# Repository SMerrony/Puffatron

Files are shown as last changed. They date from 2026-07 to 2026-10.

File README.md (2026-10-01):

# The Puffatron
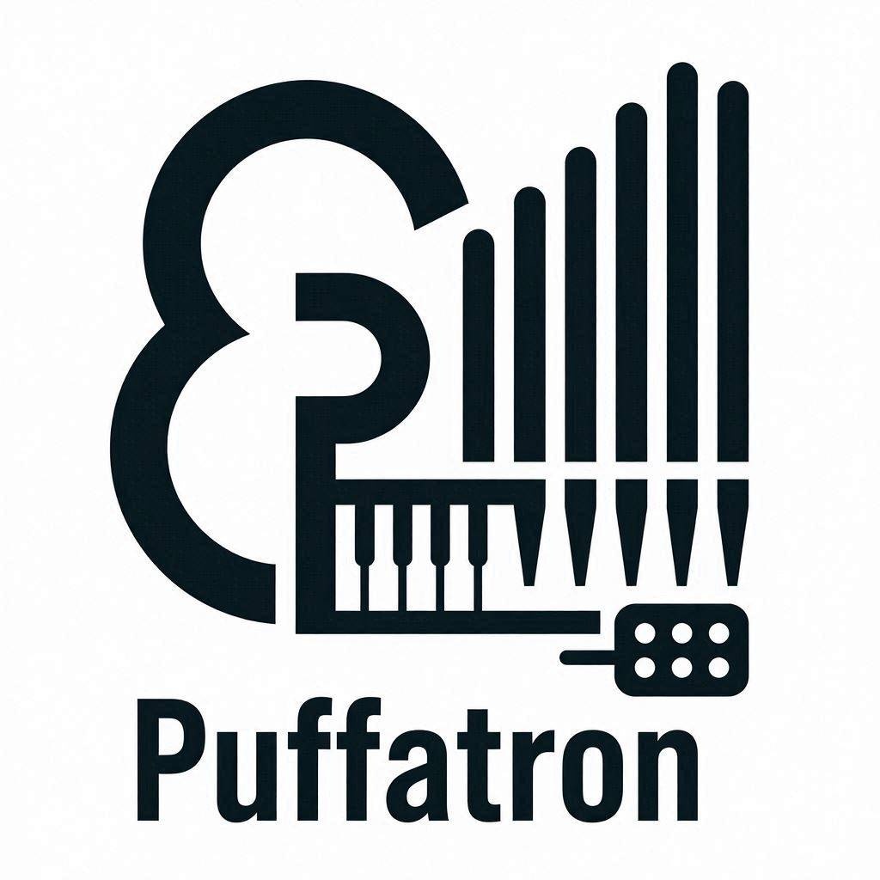
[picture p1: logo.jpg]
Puffatron Logo


The Puffatron is a mostly 3D printed USB MIDI-controlled pipe organ rank.

It can be used as a standalone USB-MIDI player, connected to MIDI keyboards to create a hybrid electronic/physical pipe organ, or added to an existing instrument as an extension.

## Features
* Easy to configure
* Active pipe display - a bit like a VU meter
* Relatively low-cost
* All the 3D printed parts are printable on a reasonably common domestic 3D printer eg. an Ender-3 KE
* All the off-the-shelf parts are easily obtainable
* Use either off-the-shelf breadboards, or a custom PCB

## Configuration
The configuration is stored in the `settings.toml` file.  All of the following settings are required...

* __MIDI_CHANNEL__ - which MIDI channel should this Puffatron play
* __LOWEST_NOTE__ - MIDI note number of lowest note playable on this Puffatron
* __HIGHEST_NOTE__ - MIDI note number of highest note playable on this Puffatron
* __DEBUG__ - set to `false` for production, `true` for development - controls debug messages, slows responsiveness of Puffatron

## Off-the-shelf Parts
* 12V or 5V mini-solenoids (one per pipe)
* WaveShare RP2040-Zero (or close equivalent)
* Adafruit PCA9685 16-channel PWM driver module (one for each 16 pipes)
* ULN2803A Darlington array (two for each 16 pipes)
* SSD1306 OLED display
* Blower...
* PSU...
* Breadboards

## 3D Printed Parts
* Windchest
* Blower box
* Pipe feet (whistles)
* Tuning slides (or corks?)
  
## Miscellaneous Parts
* Neoprene sheet
* Medium-sized metal-cored paperclips (one per pipe)
* Hook-up wire for breadboard and solenoids

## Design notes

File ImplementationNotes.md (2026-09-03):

# Puffatron

## Concept
A rank of 3D printed organ pipes, on a 3D printed wind-chest controlled via standard USB MIDI.
With 16 available MIDI channels, we could theoretically have 16 ranks/Puffatrons!

The goal is that all the 3D printed parts should be printable on a reasonably common domestic 3D printer eg. an Ender-3 KE.

## Microcontroller
The inexpensive WaveShare RP2020-PiZero has been chosen for the project.  Many similar "pico zero" type controllers should work equally well.

To handle the desired 49 - 56 notes per rank, best to use 3 expanders and some built-in GPIOs.

The 3D-printed windchest seems to max out at 33 pipes (on a 210x210mm print bed).  Maybe we could add a smaller extension to provide the full 49 - 56 pipes, i.e. an extra 16 - 23 pipes.

## Software/Firmware
As the required functionality is quite simple I have chosen to use CircuitPython which provides all the libraries needed (eg. USB MIDI, PCA9685).

## Configuration
See the README.md
  
## Wiring Conventions
By establishing the following conventions we eliminate the need for complex configuration files...

### Pipe Wiring (solenoids)
* It is assumed that all notes between HIGHEST_NOTE and LOWEST_NOTE exist.
* The LOWEST_NOTE should play via the first GPIO pin on the microcontroller.
* The next 7 notes then play sequentially on GPIO1 - GPIO7.
* If there are more than 8 notes playable, the 9th plays via the first GPIO pin of the first I2C expander.
* If there are more than 24 notes playable, the 25th plays via the first GPIO pin of the second I2C expander.
* If there are more than 40 notes playable, the 41st plays via the first GPIO pin of the third I2C expander.

### I2C Wiring
We use two I2C channels, one for the PCA9685 expanders, and one for the SSD1306 OLED display.
* The expanders connect to GPIO 28 and 29
* The display connects to GPIO 26 and 27

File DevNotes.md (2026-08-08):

# Puffatron

## Concept
A rank of 3D printed organ pipes, on a 3D printed wind-chest controlled via standard USB MIDI.
With 16 available MIDI channels, we could theoretically have 16 ranks/Puffatrons!

The goal is that all the 3D printed parts should be printable on a reasonably common domestic 3D printer eg. an Ender-3 KE.

## Microcontroller
The inexpensive WaveShare RP2020-PiZero has been chosen for the project.  Many similar "pico zero" type controllers should work equally well.

Each RP2040-Zero could potentially handle...

* 20 GPIOs using the pins only - not the pads*
* 48 GPIOs using 3 x MCP23017 16-way I2C GPIO expanders
* 66 GPIOs using 3 expanders and 18 pins
* 146 GPIOs using 8 expanders and 18 pins
* (290 GPIOs using 16 expanders (2 I2C channels) and 16 pins!)

\* But not on a standard breadboard - you can only use the 'side' pins, not the bottom ones.  The same applies to all the figures - subtract 5 local GPIOs from each count if using an off-the-shelf breadboard rather than the PCB

To handle the desired 49 - 56 notes per rank, best to use 3 expanders and some built-in GPIOs.

The 3D-printed windchest seems to max out at 33 pipes (on a 210x210mm print bed).  Maybe we could add a smaller extension to provide the full 49 - 56 pipes, i.e. an extra 16 - 23 pipes.

## Software/Firmware
As the required functionality is quite simple I have chosen to use CircuitPython which provides all the libraries needed (eg. USB MIDI, MCP23017).

## Configuration
See the README.md
  
## Wiring Conventions
By establishing the following conventions we eliminate the need for complex configuration files...

### Pipe Wiring (solenoids)
* It is assumed that all notes between HIGHEST_NOTE and LOWEST_NOTE exist.
* The LOWEST_NOTE should play via the first GPIO (GPA0) pin on the first I2C expander.
* The notes then play sequentially on that expander.
* If there are more than 16 notes playable, the 17th plays via the first GPIO pin of the second I2C expander.
* If there are more than 32 notes playable, the 33rd plays via the first GPIO pin of the third I2C expander.
* If there are more than 48 notes playable, the 47th plays via GPIO 0 on the microcontroller

### I2C Wiring
We use two I2C channels, one for the MCP23017 expanders, and one for the SSD1306 OLED display.
* The expanders connect to GPIO 28 and 29
* The display connect to GPIO 26 and 27

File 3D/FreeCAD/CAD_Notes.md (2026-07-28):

# Puffatron

## FreeCAD
Currently using FreeCAD v1.1.0

## Changes

### Action Prototype 3 2026-07-22
* Remove lever pad lip
* Chamfer wind tube

### Action Prototype 2 2026-07-22
* Add spring holes to lever and chest
* Add spring guide guide to lever
* Slightly increase hole size for solenoid
* Reduce lever length by 3mm
* Reduce some walls to 1.6mm (from 2mm)
* Increase axle holes to 2mm (from 1.8mm)

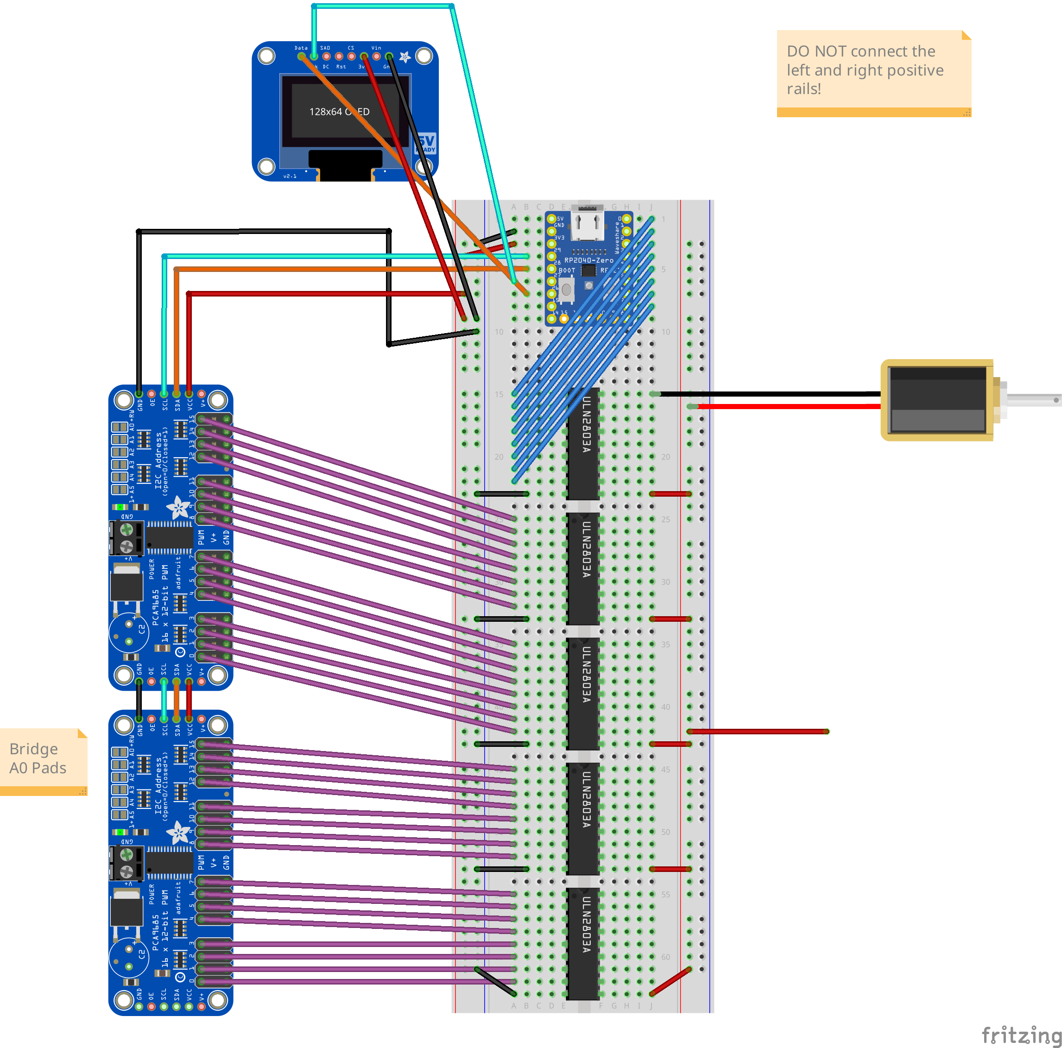
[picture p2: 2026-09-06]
PCB/Puffatron_bb.png

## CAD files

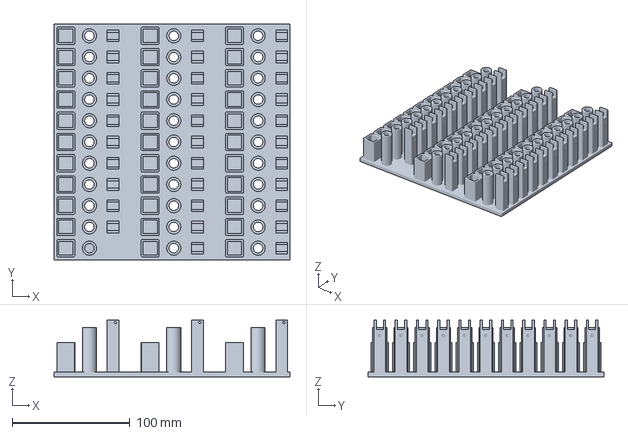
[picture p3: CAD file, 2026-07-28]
3D/3mf/WindChest-Full_Body.3mf
200.0 x 200.0 x 48.0 mm

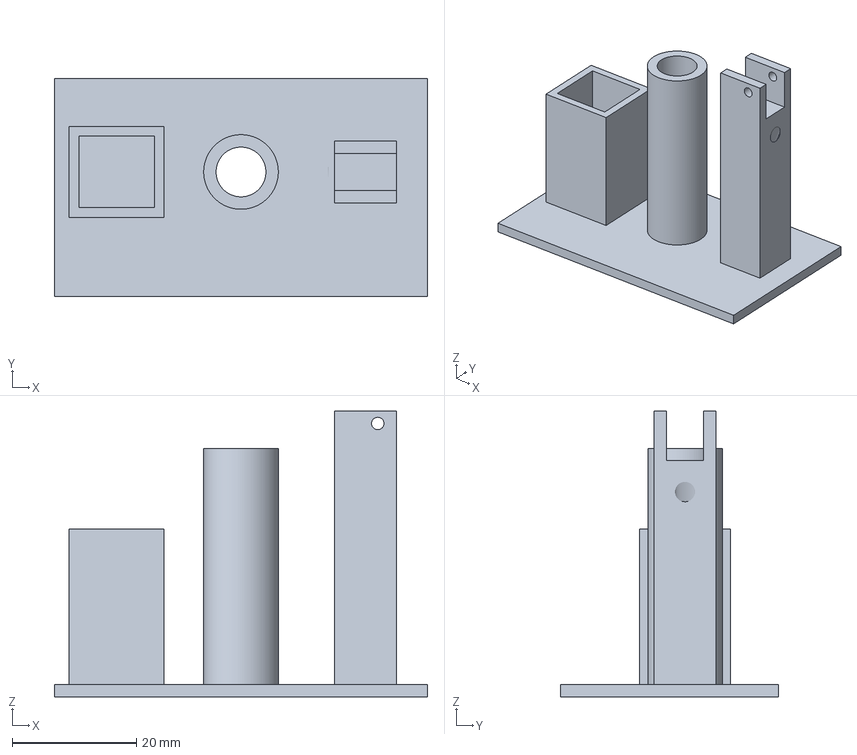
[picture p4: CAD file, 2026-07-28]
3D/3mf/WindChest-Body.3mf
60.0 x 35.0 x 46.0 mm

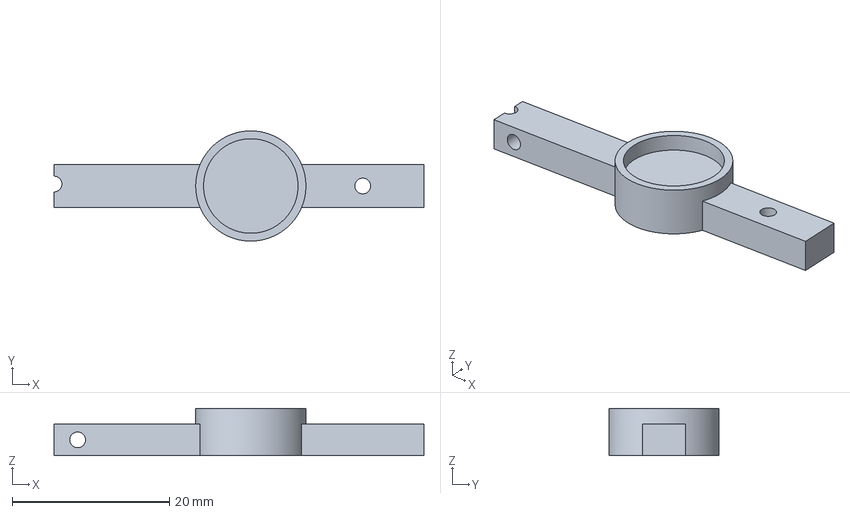
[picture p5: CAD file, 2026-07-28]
3D/3mf/WindChest-Lever.3mf
47.0 x 14.0 x 6.00 mm

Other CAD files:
3D/3mf/WindChest-BodyMultiTransform.3mf
3D/FreeCAD/WindChest.FCStd
3D/3mf/Orca_WindChest-BodyMultiTransform.3mf

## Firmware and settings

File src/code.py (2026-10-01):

# SPDX-FileCopyrightText: 2026 Stephen Merrony
# SPDX-License-Identifier: MIT

from   adafruit_display_shapes.rect import Rect
from   adafruit_display_text import label
from   adafruit_displayio_ssd1306 import SSD1306
from   adafruit_midi import MIDI
from   adafruit_midi.note_on import NoteOn
from   adafruit_midi.note_off import NoteOff
from   adafruit_midi.control_change import ControlChange
from   adafruit_pca9685 import PCA9685
import array
import board
from   busio import I2C
import displayio
from   gc import mem_free
from   i2cdisplaybus import I2CDisplayBus
from   micropython import const
import pwmio
import supervisor
from   terminalio import FONT
from   time import sleep
from   usb_midi import ports

VERSION = const("v0.0.2")

# Settings for the SSD1306 OLED display
DISP_ADDR   = const(0x3c)
DISP_HEIGHT = const(64)
DISP_WIDTH  = const(128)
DISP_BORDER = const(1)

PCA9685_CHANNELS = const(16)
ONBOARD_PIPES    = const(8)
PCA_1_LAST_PIPE  = const(24)
PCA_2_LAST_PIPE  = const(40)
PCA_3_LAST_PIPE  = const(56)

MIDI_CC_ALL_SOUND_OFF = const(120)
MIDI_CC_POLY_MODE_ON  = const(127)

# Grab the user settings 
DEBUG        = supervisor.get_setting("DEBUG")
MIDI_CHANNEL = supervisor.get_setting("MIDI_CHANNEL")
LOWEST_NOTE  = supervisor.get_setting("LOWEST_NOTE")
HIGHEST_NOTE = supervisor.get_setting("HIGHEST_NOTE")
PWM_FREQ     = supervisor.get_setting("PWM_FREQ")
ATTACK_PWM_DUTY_CYCLE = supervisor.get_setting("ATTACK_PWM_DUTY_CYCLE")
ATTACK_DURATION_MS    = supervisor.get_setting("ATTACK_DURATION_MS")
HOLD_PWM_DUTY_CYCLE   = supervisor.get_setting("HOLD_PWM_DUTY_CYCLE")

# Derive some values
NUM_NOTES = (HIGHEST_NOTE - LOWEST_NOTE) + 1
VU_COL_WIDTH = (DISP_WIDTH - (2 * DISP_BORDER)) // NUM_NOTES
VU_COL_HEIGHT = DISP_HEIGHT - (2 * DISP_BORDER)

# Other constants
PCA9685_SCK = board.GP29
PCA9685_SDA = board.GP28
SSD1306_SCK = board.GP27
SSD1306_SDA = board.GP26

PCA9685_BASE_I2C_ADDRESS = const(0x40)

UNPLAYABLE  = const(-1)
NOT_PLAYING = const(-1)

# Globals...
onboard_pipe_pwms: list[pwmio.PWMOut] = []
pcas     : list[PCA9685] = []
bar_dict = {}
note_start_ticks = array.array("i", ())

# Functions

def setup_onboard_pwm() -> None:
    "Set up the first 8 GPIOs as PWM outputs, duty_cycle set to 0 to ensure no note plays at startup"
    onboard_pipe_pwms.append(pwmio.PWMOut(pin=board.GP0, duty_cycle=0, frequency=PWM_FREQ))
    onboard_pipe_pwms.append(pwmio.PWMOut(pin=board.GP1, duty_cycle=0, frequency=PWM_FREQ))
    onboard_pipe_pwms.append(pwmio.PWMOut(pin=board.GP2, duty_cycle=0, frequency=PWM_FREQ))
    onboard_pipe_pwms.append(pwmio.PWMOut(pin=board.GP3, duty_cycle=0, frequency=PWM_FREQ))
    onboard_pipe_pwms.append(pwmio.PWMOut(pin=board.GP4, duty_cycle=0, frequency=PWM_FREQ))
    onboard_pipe_pwms.append(pwmio.PWMOut(pin=board.GP5, duty_cycle=0, frequency=PWM_FREQ))
    onboard_pipe_pwms.append(pwmio.PWMOut(pin=board.GP6, duty_cycle=0, frequency=PWM_FREQ))
    onboard_pipe_pwms.append(pwmio.PWMOut(pin=board.GP7, duty_cycle=0, frequency=PWM_FREQ))

def init_note_start_times() -> None:
    "Create the array of start times for each playable note and set them to NOT_PLAYING"
    for t in range(LOWEST_NOTE, HIGHEST_NOTE + 1):
        note_start_ticks.append(NOT_PLAYING)

_TICKS_PERIOD = 1<<29
_TICKS_MAX = _TICKS_PERIOD - 1
_TICKS_HALFPERIOD =_TICKS_PERIOD // 2

def ticks_diff(ticks1, ticks2):
    "Compute the signed difference between two ticks values, assuming that they are within 2**28 ticks"
    diff = (ticks1 - ticks2) & _TICKS_MAX
    diff = ((diff + _TICKS_HALFPERIOD) & _TICKS_MAX) - _TICKS_HALFPERIOD
    return diff

def setup_pca9685(ix : int) -> PCA9685:
    "Set up a single PCA9685 and set all its duty_cycles to 0 to ensure no note plays at startup"
    i2c = I2C(PCA9685_SCK, PCA9685_SDA)
    pca = PCA9685(i2c_bus=i2c, address=PCA9685_BASE_I2C_ADDRESS + ix)
    pca.frequency = PWM_FREQ
    for c in range(0, PCA9685_CHANNELS):
        pca.channels[c].duty_cycle = 0
    return pca

def setup_pipe_display() -> None:
    "Build a dict of all possible bars for the VU meter, this stores the images in the bar_dict"
    for bar in range(LOWEST_NOTE, HIGHEST_NOTE + 1):
        adjusted_note = bar - LOWEST_NOTE
        x_left = adjusted_note * VU_COL_WIDTH
        if NUM_NOTES < (VU_COL_HEIGHT / 2):
            adjusted_note *= 2
        bar_dict[bar] = Rect(
            x_left, 
            DISP_BORDER + adjusted_note, 
            VU_COL_WIDTH, 
            VU_COL_HEIGHT - adjusted_note, 
            fill=0xffffff)

def setup_ssd1306_display() -> displayio.Group:
    displayio.release_displays()
    i2c = I2C(SSD1306_SCK, SSD1306_SDA)
    display_bus = I2CDisplayBus(i2c, device_address=DISP_ADDR)
    display = SSD1306(display_bus, width=DISP_WIDTH, height=DISP_HEIGHT)
    # Make the display context
    screen = displayio.Group()
    display.root_group = screen
    return screen

def setup_midi(channel : int) -> MIDI:
    midi = MIDI(
        midi_in = ports[0], # type: ignore
        midi_out = None,
        in_channel = channel
        )
    return midi

def splash(scr : displayio.Group) -> None:
    app_label = label.Label(
        FONT,
        x = 10, y = 12,
        text="Puffatron",
        color=0,
        scale=2,
        padding_left=1, padding_top=0,
        background_color=0xffffff
    )
    scr.append(app_label)
    version_label = label.Label(
        FONT,
        x = 30, y = 40,
        text=VERSION,
        scale=2,
        padding_left=1, padding_top=0,
    )
    scr.append(version_label)
    sleep(2)
    scr.remove(version_label)
    scr.remove(app_label)

def playable(note_num : int) -> bool:
    if note_num < LOWEST_NOTE or note_num > HIGHEST_NOTE:
        return False
    else:
        return True

def start_note(note_num : int) -> None:
    note_ix = note_num - LOWEST_NOTE
    if note_start_ticks[note_ix] == NOT_PLAYING:
        note_start_ticks[note_ix] = supervisor.ticks_ms()
        if note_ix < ONBOARD_PIPES:
            onboard_pipe_pwms[note_ix].duty_cycle = ATTACK_PWM_DUTY_CYCLE
        elif note_ix < PCA_1_LAST_PIPE:
            pcas[0].channels[note_ix - ONBOARD_PIPES].duty_cycle = ATTACK_PWM_DUTY_CYCLE
        elif note_ix < PCA_2_LAST_PIPE:
            pcas[1].channels[note_ix - PCA_1_LAST_PIPE].duty_cycle = ATTACK_PWM_DUTY_CYCLE
        elif note_ix < PCA_3_LAST_PIPE:
            pcas[2].channels[note_ix - PCA_2_LAST_PIPE].duty_cycle = ATTACK_PWM_DUTY_CYCLE

def stop_note(note_num :int) -> None:
    note_ix = note_num - LOWEST_NOTE
    if note_start_ticks[note_ix] != NOT_PLAYING:
        note_start_ticks[note_ix] = NOT_PLAYING
        if note_ix < ONBOARD_PIPES:
            onboard_pipe_pwms[note_ix].duty_cycle = 0
        elif note_ix < PCA_1_LAST_PIPE:
            pcas[0].channels[note_ix - ONBOARD_PIPES].duty_cycle = 0
        elif note_ix < PCA_2_LAST_PIPE:
            pcas[1].channels[note_ix - PCA_1_LAST_PIPE].duty_cycle = 0
        elif note_ix < PCA_3_LAST_PIPE:
            pcas[2].channels[note_ix - PCA_2_LAST_PIPE].duty_cycle = 0

def stop_all_notes() -> None:
    n = LOWEST_NOTE
    while n <= HIGHEST_NOTE: 
        stop_note(n)
        n += 1

# **** Main code starts here **** #

screen = setup_ssd1306_display()
if DEBUG: print("Free memory: ", mem_free())
splash(screen)
setup_pipe_display()
midi = setup_midi(MIDI_CHANNEL)
setup_onboard_pwm()
if NUM_NOTES > ONBOARD_PIPES:
    pcas.append(setup_pca9685(0))
if NUM_NOTES > PCA_1_LAST_PIPE:
    pcas.append(setup_pca9685(1))
if NUM_NOTES > PCA_2_LAST_PIPE:
    pcas.append(setup_pca9685(2))
if DEBUG: print(len(pcas), " PCA9685 units initialised")

init_note_start_times()

if DEBUG: print("Free memory: ", mem_free())
print("Puffatron ready...") 

while True:
    msg = midi.receive() # <--- This does not block
    if isinstance(msg, NoteOn) and msg.velocity != 0:
        if DEBUG: print("Note On:  ", msg.note, " velocity: ", msg.velocity)
        if playable(msg.note):
            start_note(msg.note) 
            # The error handling below is for the rare case when we get two Note Ons for the same note
            try:
                screen.append(bar_dict[msg.note])
            except:
                if DEBUG: print("Error drawing a VU bar which was already there")
                
    elif isinstance(msg, NoteOff) or (isinstance(msg, NoteOn) and msg.velocity == 0):
        if DEBUG: print("Note Off: ", msg.note)
        if playable(msg.note):
            stop_note(msg.note)
            # The error handling below deals with the rare case where we might get a Note Off without
            # having received a corresponding Note On.
            try:
                screen.remove(bar_dict[msg.note])
            except:
                if DEBUG: print("Error removing VU bar which didn't exist")
        if DEBUG: print("Free memory: ", mem_free())
        
    elif isinstance(msg, ControlChange):
        if msg.control >= MIDI_CC_ALL_SOUND_OFF and msg.control <= MIDI_CC_POLY_MODE_ON:
            if DEBUG: print("All notes off/panic")
            stop_all_notes()
            
    # check if any notes need to move from attack to hold phase...
    now = supervisor.ticks_ms()
    for note_ix in range(0, len(note_start_ticks)):
        if note_start_ticks[note_ix] != NOT_PLAYING:
            if ticks_diff(now, note_start_ticks[note_ix]) > ATTACK_DURATION_MS:
                if note_ix < ONBOARD_PIPES:
                    if onboard_pipe_pwms[note_ix].duty_cycle == ATTACK_PWM_DUTY_CYCLE:
                        if DEBUG: print("Moving pipe to HOLD phase: ", note_ix)
                        onboard_pipe_pwms[note_ix].duty_cycle = HOLD_PWM_DUTY_CYCLE
                elif note_ix < PCA_1_LAST_PIPE:
                    if pcas[0].channels[note_ix - ONBOARD_PIPES].duty_cycle == ATTACK_PWM_DUTY_CYCLE:
                        if DEBUG: print("Moving pipe to HOLD phase: ", note_ix)
                        pcas[0].channels[note_ix - 8].duty_cycle = HOLD_PWM_DUTY_CYCLE
                elif note_ix < PCA_2_LAST_PIPE:
                    if pcas[1].channels[note_ix - PCA_1_LAST_PIPE].duty_cycle == ATTACK_PWM_DUTY_CYCLE:
                        pcas[1].channels[note_ix - PCA_1_LAST_PIPE].duty_cycle = HOLD_PWM_DUTY_CYCLE
                elif note_ix < PCA_3_LAST_PIPE:
                    if pcas[2].channels[note_ix - PCA_2_LAST_PIPE].duty_cycle == ATTACK_PWM_DUTY_CYCLE:
                        pcas[2].channels[note_ix - PCA_2_LAST_PIPE].duty_cycle = HOLD_PWM_DUTY_CYCLE
  

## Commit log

2026-08-05 Add KiCAD diagram, add "VU meter"
    [Puffatron.kicad_pcb, Puffatron.kicad_sch]
2026-08-06 Pre-build a dict of bars for the "VU meter" - to avoid eating memory.
    [code.py]
2026-08-06 Catch error when getting a NoteOff without previous NoteOn
    [code.py]
2026-08-07 Reorg code, update schematic and README
    [Puffatron.kicad_sch]
2026-08-08 Add I2C constants, correct schematic, uptdate docs
    [Puffatron.csv, Puffatron.kicad_sch]
2026-09-03 End of work on first version - changing approach to use external PWM modules.
    [Puffatron.fzz]
2026-09-03 Start on second version using different I2C expanders...
2026-09-03 First success with solenoid
    [Puffatron.fzz]
2026-09-06 Use Fritzing rather than KiCad for the layout
    [Puffatron.csv, Puffatron.fzz, Puffatron.kicad_pcb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]
2026-09-06 Update 3D model adding chamfer and vents
    [Orca_WindChest-BodyMultiTransform.3mf, WindChest-BodyMultiTransform.3mf, WindChest.FCStd]
